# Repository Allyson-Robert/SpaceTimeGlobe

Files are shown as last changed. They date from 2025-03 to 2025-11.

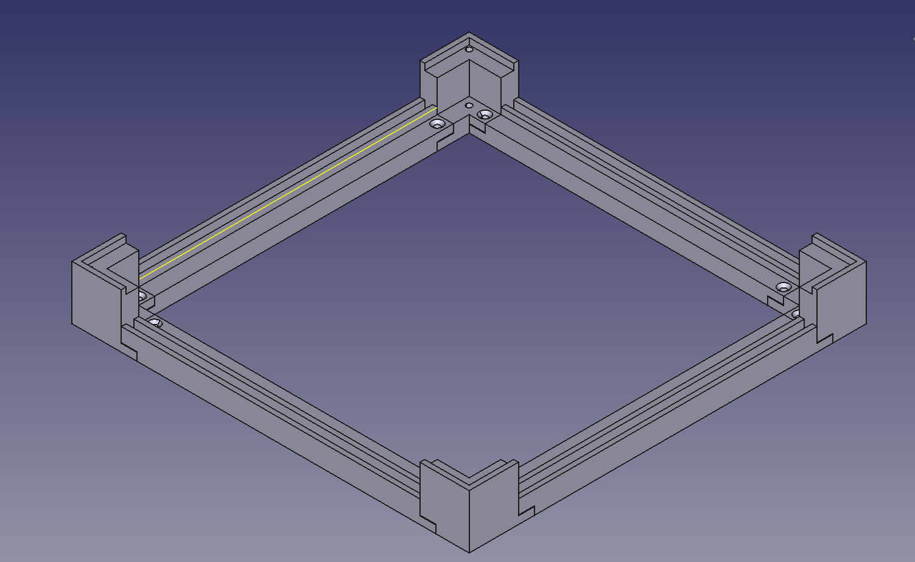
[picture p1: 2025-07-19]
Images/Corners-Edges.png

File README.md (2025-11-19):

# 🌌 SpaceTimeGlobe

A buildable **3D spacetime globe** model for 3D printing and laser cutting.
Assemble a sleek, transparent globe that illustrates spacetime geometry using simple bolts, rods, and laser-cut plates.

---

## 🧩 What’s Included

From the `repository_root/` you’ll find:

* STEP/STL files: supportless print-ready (use STLs if your CAD software or slicer has issues with the STEP files)
* Reference images: `006.png`, `008.png`, and others
* Plates for laser‑cutting
* FreeCAD Model Files
  * **Corner and edge 3D‑printable frames**

    * `corner_piece_*` (x 4)
    * `edge_piece_*` (x 4)

    * `hyperbola_plate.svg/.dxf` (4 mm low‑friction material, e.g., plexiglass)
    * `top_plate.svg/.dxf` (4 mm transparent plexiglass)
  * **Lattice blocks** (designed for 3D printing)
  * **Assembly.FCStd** – example with 4 lattice blocks
  * Full FreeCAD source files

    * `Dimensions.FCStd` – size‐reference file
    * Other FCStd models update automatically when reopened & recomputed

---

## 🛠️ Hardware & Materials Needed

* **M3 × 10 mm countersunk bolts and nuts**

  * \~12 for frame assembly, plus \~8 for plates
* **Laser-cut plates:**

  * Hyperbola plate: 4 mm low‑friction material (plexiglass suggested)
  * Top plate: 4 mm transparent plexiglass
* **Aluminium rods:** 6 mm diameter × 25 mm long (quantity depends on lattice blocks)
* Optional: lattice-block pins (not every block requires one)

---

## 🧭 Assembly Instructions

### 1. Frame Assembly

1. Print 4 corner pieces and 4 edge pieces.
2. Align and bolt into a cube-style frame using M3 × 10 mm countersunk bolts from the top, nuts secured underneath.
3. Ensure all nuts are seated flush in the bottom holes.

### 2. Hyperbola Plate

1. Laser-cut plate
2. Carefully countersink the four pre-lasered bolt holes.
3. Bolt the plate onto the assembled frame using M3 × 10 bolts and nuts.

### 3. Lattice Blocks & Rods

1. 3D print the default 16 lattice blocks (as in design).
2. Refer to `006.png` to insert the 6 mm × 25 mm aluminium rods through the blocks.
3. Only some blocks require pins—these are optional and not shown; customize per your design.

### 4. Top Plate

1. Laser-cut with the provided design (again, adjust if globally resized).
2. Bolt into position over the lattice‑rod assembly using M3 × 10 bolts and nuts.

### 5. Final Check

See `Assembly.FCStd` and `008.png` for a visual example with four blocks. Ensure bolts are snug and rods slide freely.

---

## 🛠️ Customizing Sizes

* Modify **only** `Dimensions.FCStd` (your master parameter file).
* Re-open every other `.FCStd` file afterward and click “Recompute” so they reflect the new size.
* Re-export STEP files and laser files as needed for printing or cutting.

---

## 🧠 Tips & Notes

* Always countersink bolt holes in laser-cut parts for flush mounting.
* For altered dimensions, change the Dimenions.FCStd file and recompute all other files
* Lattice-block pin placement is a bit of a mess atm but I do not have the diagram ready yet. Not all blocks should have a pin.

---

## 🎯 Quick Start Checklist

* [ ] Print 4 corner + 4 edge pieces
* [ ] Laser-cut hyperbola + top plates
* [ ] Assemble frame with M3 bolts & nuts
* [ ] Attach hyperbola plate
* [ ] Print lattice blocks and insert rods
* [ ] Bolt on top plate
* [ ] Enjoy your SpaceTimeGlobe!

---

Feel free to tweak as needed—and congratulations on this beautiful functional design!

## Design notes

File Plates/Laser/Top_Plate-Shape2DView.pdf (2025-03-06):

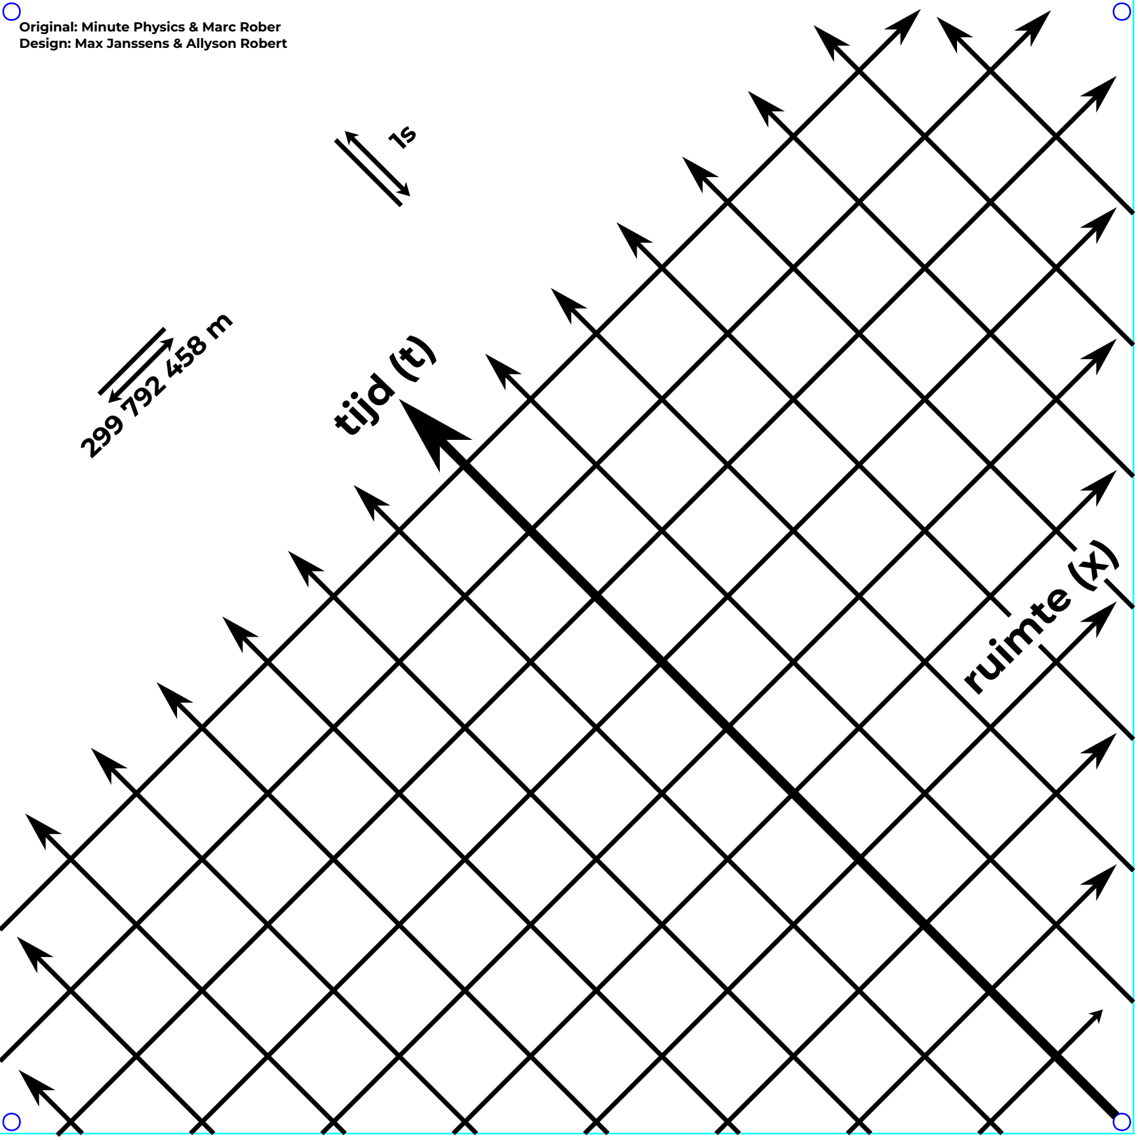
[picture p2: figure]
tijd (t); ruimte (x); Original: Minute Physics & Marc Rober

Design: Max Janssens & Allyson Robert 299 792 458 m

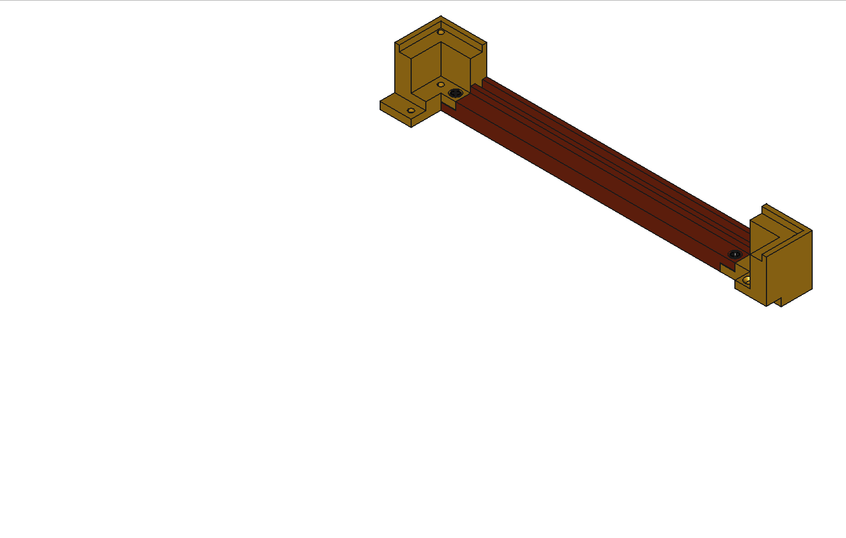
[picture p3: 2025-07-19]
Images/001-B.png

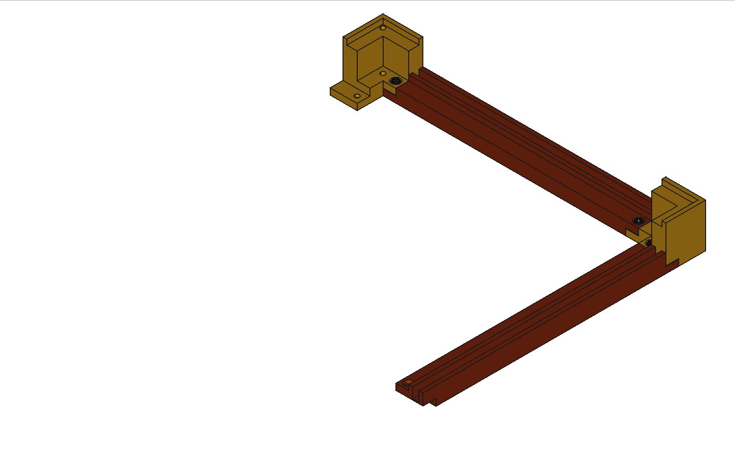
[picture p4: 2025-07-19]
Images/001-C.png

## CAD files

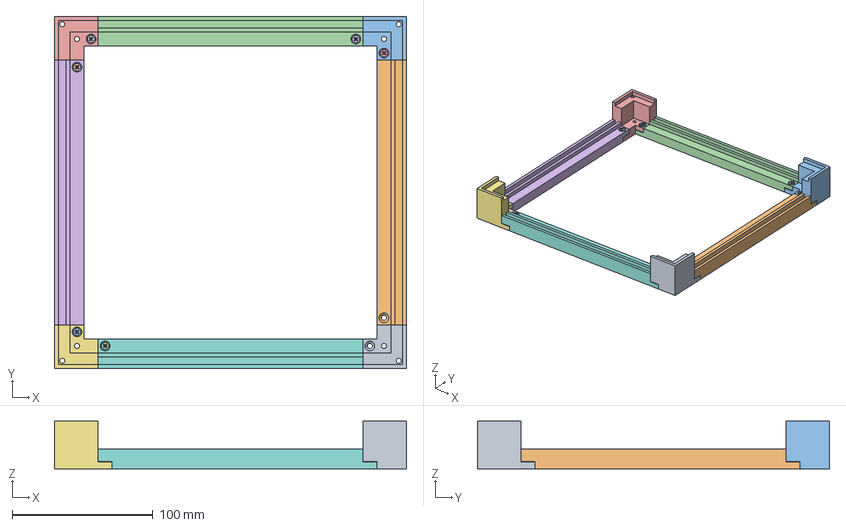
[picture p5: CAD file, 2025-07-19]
Models/Assembly.FCStd
250.0 x 250.0 x 34.0 mm
SpaceTimeGlobe_Border_Corner_001
Spacetime_Globe_Border_Edge_001
SpaceTimeGlobe_Border_Corner_002
Spacetime_Globe_Border_Edge_002
SpaceTimeGlobe_Border_Corner_003
Spacetime_Globe_Border_Edge_003
SpaceTimeGlobe_Border_Corner_004
Spacetime_Globe_Border_Edge_004
M3x10-Screw
M3x10-Screw064
M3x10-Screw065
M3x10-Screw066
M3x10-Screw067
M3x10-Screw068

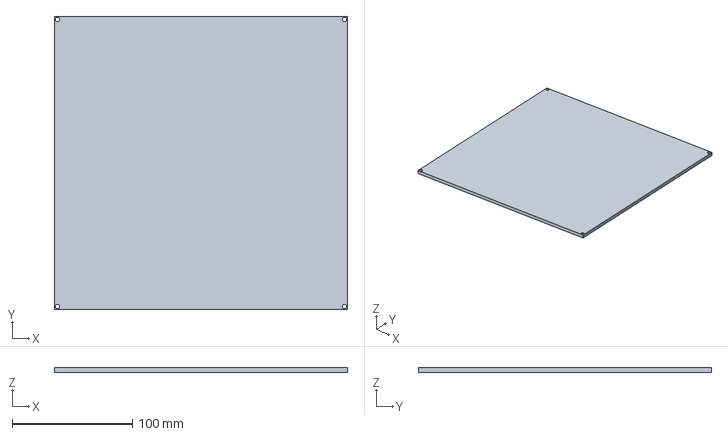
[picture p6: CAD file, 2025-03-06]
Plates/Model/Top_Plate.FCStd
244.0 x 244.0 x 4.00 mm

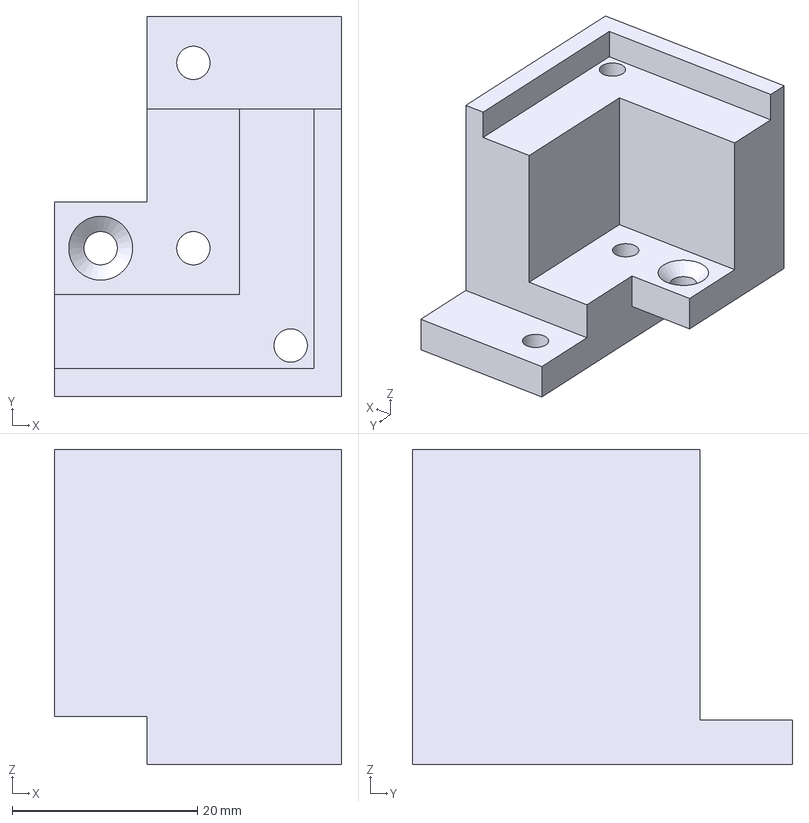
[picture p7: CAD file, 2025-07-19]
STEP-files/SpaceTimeGlobe_Border_Corner.step
31.0 x 41.0 x 34.0 mm

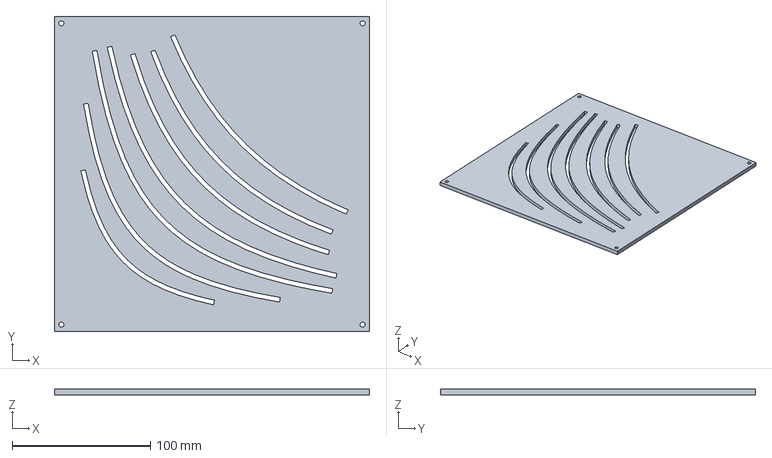
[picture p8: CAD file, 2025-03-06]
Plates/Model/Hyperbola_Plate.FCStd
228.0 x 228.0 x 4.00 mm

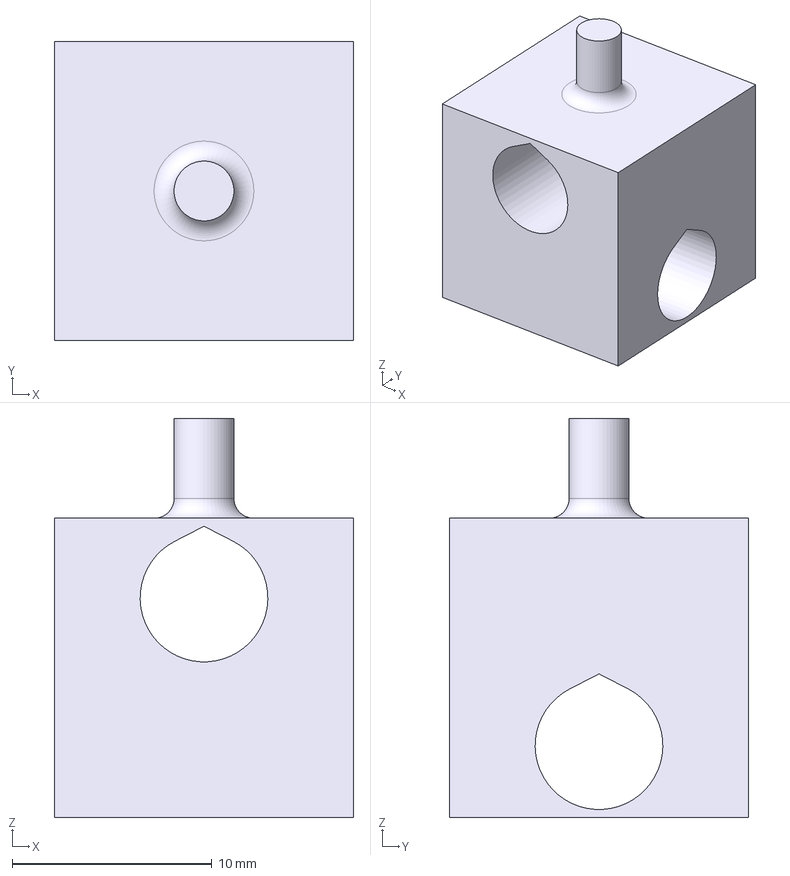
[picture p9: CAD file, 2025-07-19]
STEP-files/SpaceTimeGlobe_Lattice_Block.step
15.0 x 15.0 x 20.0 mm

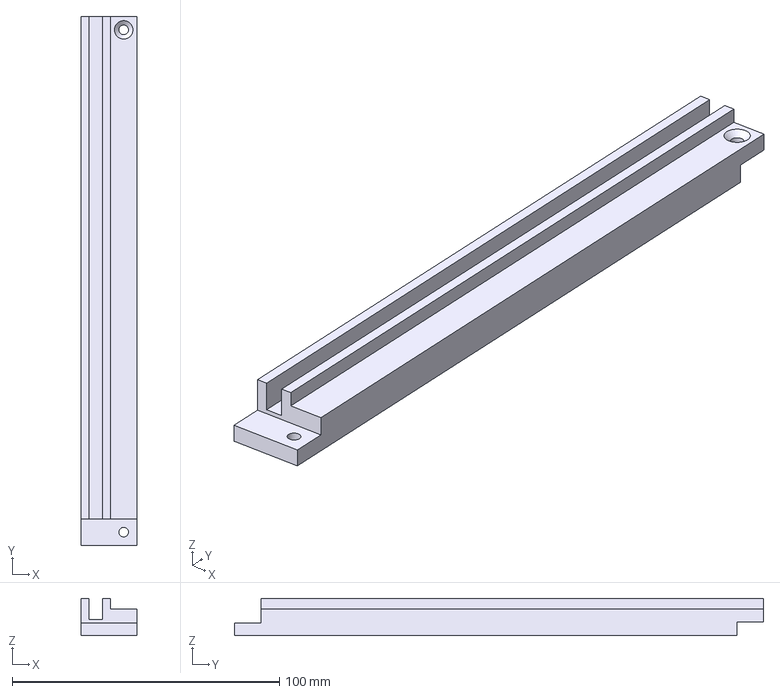
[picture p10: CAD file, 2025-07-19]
STEP-files/Spacetime_Globe_Border_Edge.step
21.0 x 198.0 x 14.0 mm

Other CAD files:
Models/Dimensions.FCStd
Models/SpaceTimeGlobe_Border_Corner.FCStd
Models/SpaceTimeGlobe_Lattice_Block.FCStd
Models/Spacetime_Globe_Border_Edge.FCStd
STL-files/SpaceTimeGlobe_Border_Corner.stl
STL-files/SpaceTimeGlobe_Lattice_Block-pinless.stl
STL-files/SpaceTimeGlobe_Lattice_Block.stl
STL-files/Spacetime_Globe_Border_Edge.stl

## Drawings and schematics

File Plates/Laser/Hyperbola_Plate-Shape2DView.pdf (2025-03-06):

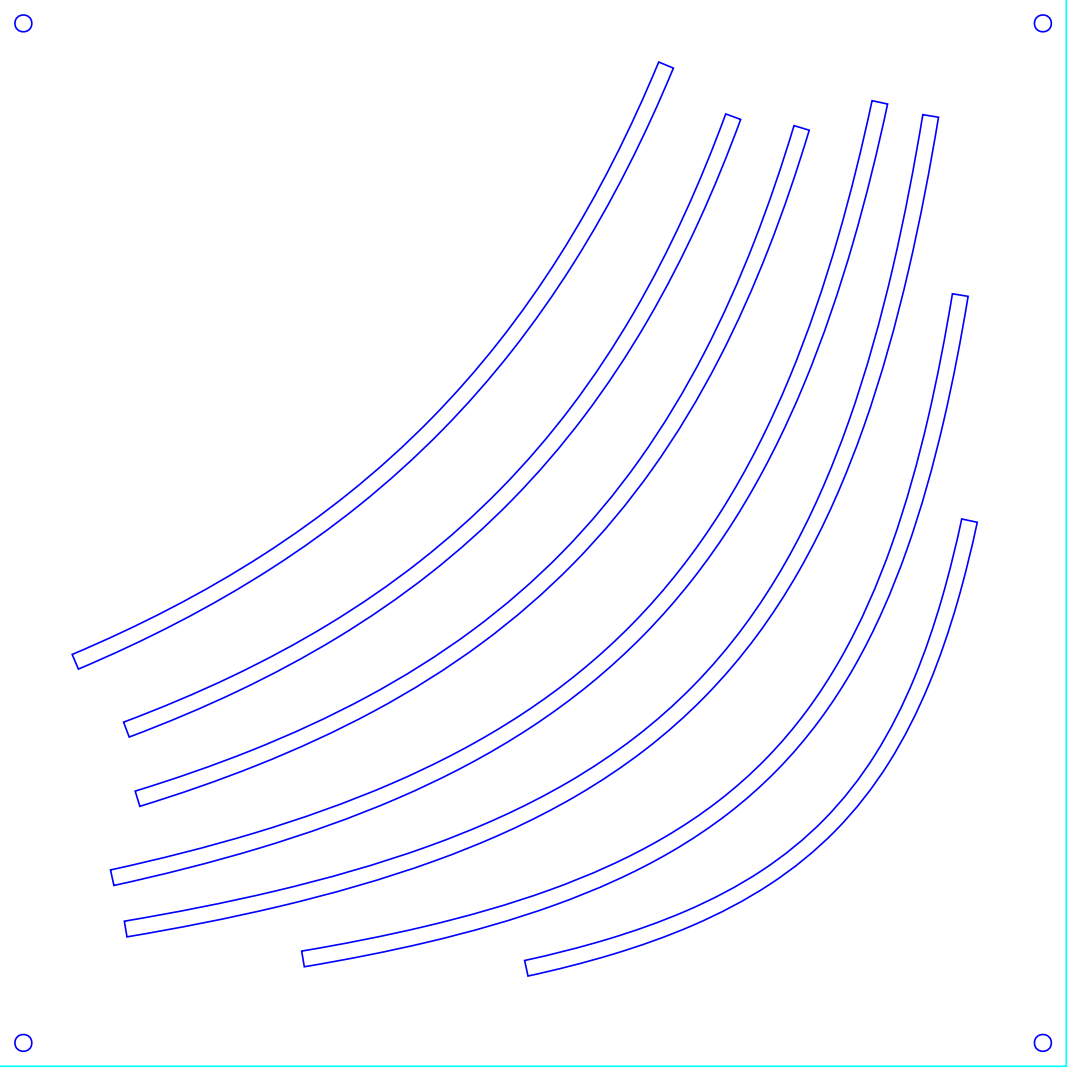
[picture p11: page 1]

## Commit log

2024-12-27 Started Assembly.FCStd to collect all dims, prepped subdirs per part
    [Assembly.FCStd]
2024-12-27 Border edge part added
    [Spacetime_Globe_Border_Edge.FCStd]
2024-12-27 fixed gitignore and added Assembly
    [Assembly.FCStd]
2025-01-11 Corner piece first draft
    [SpaceTimeGlobe_Border_Corner.FCStd]
2025-01-11 Referencing the Assembly file for dimensions
    [Spacetime_Globe_Border_Edge.FCStd]
2025-01-11 Contains dimensions and imports for final assembly
    [Assembly.FCStd]
2025-01-11 Plate has dimensions from assembly
    [Plate.FCStd]
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2025-01-11 Changed the part that holds the anchor
    [Spacetime_Globe_Border_Edge.FCStd]
2025-01-11 Looks like I forced circularity by trying to assemble in the file containing the dimensions
    [Prototype_Assembly.FCStd]
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2025-01-11 Demonstrate change of dimensions by changing edge from 10 cm to 15 cm
    [Assembly.FCStd, Prototype_Assembly.FCStd, SpaceTimeGlobe_Border_Corner.FCStd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]
2025-01-11 modified the screw holes in the edge and corner pieces
    [Assembly.FCStd, Prototype_Assembly.FCStd, SpaceTimeGlobe_Border_Corner.FCStd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]
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2025-01-11 refactor Assembly.FCStd --> Dimensions.FCStd
    [Dimensions.FCStd, Plate.FCStd, Prototype_Assembly.FCStd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]
2025-01-12 Bigger bolt shaft diameter, deeper countersink, compensation added because of poor overhang print quality
    [Dimensions.FCStd, Prototype_Assembly.FCStd, SpaceTimeGlobe_Border_Corner.FCStd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]
2025-01-12 Second test had too much clearance, bolt protruded 0.8mm on the bottom
    [Dimensions.FCStd]
2025-01-18 Changing dimensions to make the plate as large as possible given a 25cm long rod
    [Dimensions.FCStd, Prototype_Assembly.FCStd, SpaceTimeGlobe_Border_Corner.FCStd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]
2025-01-18 Changing dimensions to make the plate as large as possible given a 25cm long rod, added screwholes to plate
    [Dimensions.FCStd, Plate.FCStd, Prototype_Assembly.FCStd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]
2025-01-18 Drew hyperbolea on plate and exported
    [Plate.FCStd, Prototype_Assembly.FCStd]
2025-01-18 Changed corner and edge to have their tops flush with the plate
    [Dimensions.FCStd, Prototype_Assembly.FCStd, SpaceTimeGlobe_Border_Corner.FCStd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]
2025-01-18 Added block to prototype CAD
    [Prototype_Assembly.FCStd]
2025-01-19 File showed first step
    [Spacetime_Globe_Border_Edge.FCStd]
2025-01-19 Exported new steps for testprint
    [SpaceTimeGlobe_Border_Corner.step, Spacetime_Globe_Border_Edge.step]
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2025-01-19 Hole is a bit tight when using the prusa, also unconvinced by a 3mm pin, updated to 5 mm
    [Dimensions.FCStd, SpaceTimeGlobe_Lattice_Block.FCStd]
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2025-01-25 First version of the anchoring block
    [Dimensions.FCStd, SpaceTimeGlobe_Anchor_Block.FCStd]
2025-01-25 Added space for a bolt and a nut pocket to tighten against the rods
    [SpaceTimeGlobe_Anchor_Block.FCStd, SpaceTimeGlobe_Anchor_Block.step]
2025-01-25 Removed equality between holes so they can easily be resized independently if needed
    [SpaceTimeGlobe_Anchor_Block.FCStd]
2025-01-25 Edited to host a top plate
    [SpaceTimeGlobe_Border_Corner.FCStd]
2025-01-25 Added a representation of the cover plate that'll have a grid engraved
    [Graph_Plate.FCStd, Prototype_Assembly.FCStd]
2025-01-25 Corners need to be taller
    [Dimensions.FCStd, SpaceTimeGlobe_Border_Corner.FCStd]
2025-01-26 Added close running clearance fit for the nut
    [Dimensions.FCStd, SpaceTimeGlobe_Anchor_Block.FCStd]
2025-01-26 Redesigning the anchors to be two properly dimensioned parts
    [Dimensions.FCStd, SpaceTimeGlobe_Anchor_Block.FCStd]
2025-01-26 Manually sized for 5mm rod, Sketch007 must be repositioned after having chosen a deeper depth for the anchors
    [SpaceTimeGlobe_Anchor_Block.FCStd]
2025-01-28 Changed to two separate designs for the anchor blocks. Both versions depend on a common base.
    [Dimensions.FCStd, SpaceTimeGlobe_Anchor_Block-Bottom.step, SpaceTimeGlobe_Anchor_Block-Top.step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]
2025-01-29 Dialing in tolerances
    [Dimensions.FCStd, SpaceTimeGlobe_Anchor_Block-Bottom.step, SpaceTimeGlobe_Anchor_Block.FCStd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]
2025-02-01 Dialing in tolerances, looser tolerances are needed, step file out of sync
    [Dimensions.FCStd, SpaceTimeGlobe_Lattice_Block.FCStd, SpaceTimeGlobe_Lattice_Block.step]
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2025-03-04 New plate has 6 hyperbolea (7th is dropped, assumed to be redundant)
    [Plate.FCStd]
2025-03-04 Renamed plate sketches to have consistent numbering for the hyperbolae
    [Plate.FCStd]
2025-03-04 Idk what changed, last thing was exporting a DXF
    [Plate.FCStd]
2025-03-04 Original export through techdraw had thick lines, exported the wireframe to dxf instead
    [Plate-BodySubtractivePipe005.dxf]
2025-03-04 Exported from DXF (I think), not exact but close enough
    [Plate-grid.dxf]
2025-03-04 Added measurements --> Origin issue identified, this needs to be remade
    [Plate.FCStd]
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2025-03-05 Changed graph plate bolt position to be at the spacetime diagram origin
    [Prototype_Assembly.FCStd, SpaceTimeGlobe_Border_Corner.FCStd]
2025-03-05 redesign with new originm
    [Plate.FCStd]
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2025-03-05 Shortened the corner blocks to their minimal dimension
    [Dimensions.FCStd, Plate.FCStd, Prototype_Assembly.FCStd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]
2025-03-05 Smaller anchor width and anchor support width, new plate
    [Dimensions.FCStd, Plate.FCStd, Prototype_Assembly.FCStd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]
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2025-03-06 Plate ready for laser, steps: Shape 2D View from proper angle, export to DXF, combine paths, select all nodes, join nodes
    [Plate-BodySubtractivePipe005.dxf, Plate-Shape2DView.dxf, Plate-grid.dxf]
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2025-07-19 Anchor blocks caused the system to bind, needs a different approach
    [SpaceTimeGlobe_Anchor_Block-Bottom.step, SpaceTimeGlobe_Anchor_Block-Top.step, SpaceTimeGlobe_Anchor_Block.FCStd]
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2025-07-19 dxf andsvg are not useful and might confuse users
    [Graph_Plate-Shape2DView.dxf, Plate-Shape2DView.dxf]
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2025-11-05 Restructured into model and STEP directories for ease of finding the printable files
    [Assembly.FCStd, Dimensions.FCStd, SpaceTimeGlobe_Border_Corner.FCStd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]
2025-11-05 Restructured the Plates dir into two subdirs, one for models, one for laser-ready PDF files
    [Hyperbola_Plate.FCStd, Top_Plate.FCStd]
2025-11-07 Added STLs since some slicers might not be able to slice STEPs
    [SpaceTimeGlobe_Border_Corner.stl, SpaceTimeGlobe_Lattice_Block-pinless.stl, SpaceTimeGlobe_Lattice_Block.stl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]
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
